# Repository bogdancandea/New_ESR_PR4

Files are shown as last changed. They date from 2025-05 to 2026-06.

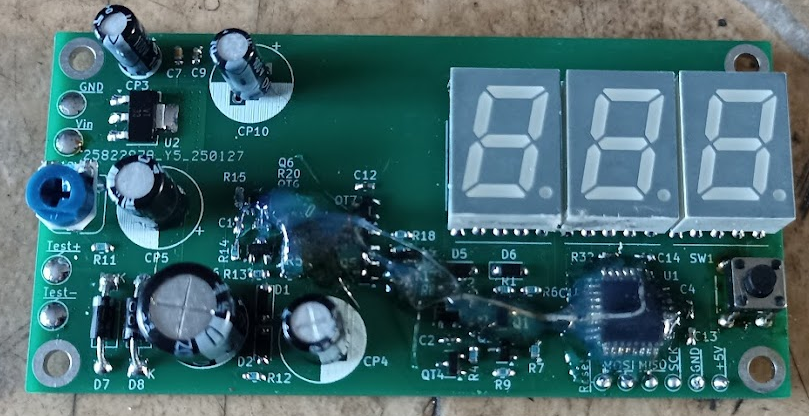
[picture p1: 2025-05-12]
1st build.png

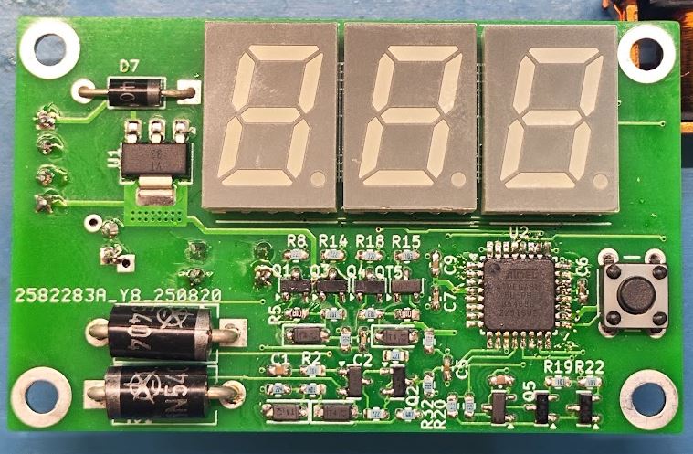
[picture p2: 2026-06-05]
v2 top.jpg

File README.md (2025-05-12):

# New_ESR_PR4
A redesigned PCB for the original ESR-PR4 ESR meter

Back in 2023, my ESR-PR4 broke due to an error (I measured a charged capacitor). My first thought was: oh well, it served me well until now—I'll just get another one. Identical.
However, over the years, the manufacturer had stopped production, and even the website had disappeared.

With some information from specialized forums and with the help of https://web.archive.org, I managed to access an archived version of the website that used to sell the product:

https://web.archive.org/web/20180327142201/http://x-roast.home.ro/

At that time, the author had published both the schematic and the software written for the microcontroller. So I was able to repair my device by replacing and reprogramming the microcontroller.

That’s when I got the idea to republish the information. Since the original information did not include the PCB, I designed a PCB version so that electronics enthusiasts could build the device themselves.

The author of the schematic and the software is unknown to me. I am using and republishing this information because it was publicly available at x-roast.home.ro. I have no commercial interest whatsoever.

There is a mismatch between the original schematic and the HEX file: pins 10 and 11 of the microcontroller are swapped.
The first unit I built had a few errors, including the swapped pins 10 and 11, which were fixed by cutting PCB traces and soldering wires.

The published version has already been corrected.

A new, smaller PCB version is currently in development, which I will publish only after I have had the chance to test it.

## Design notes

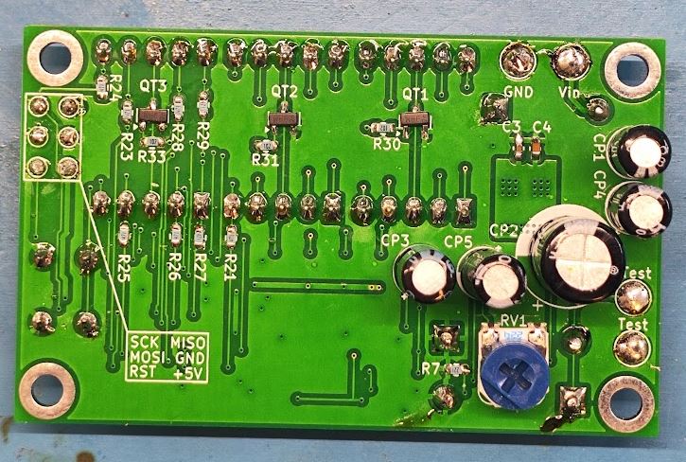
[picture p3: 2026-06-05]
v2 bottom.jpg

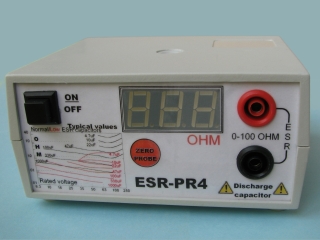
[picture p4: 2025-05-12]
originals/webarchive/ESR metru_ ESR-PR4_files/ESR-METRU ESR-PR4_proto2.JPG

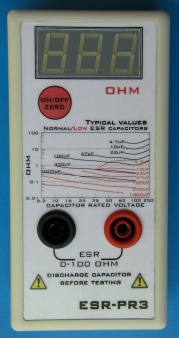
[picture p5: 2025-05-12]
originals/webarchive/ESR metru_ ESR-PR3_files/ESR-METRU ESR-PR3 front view.jpg

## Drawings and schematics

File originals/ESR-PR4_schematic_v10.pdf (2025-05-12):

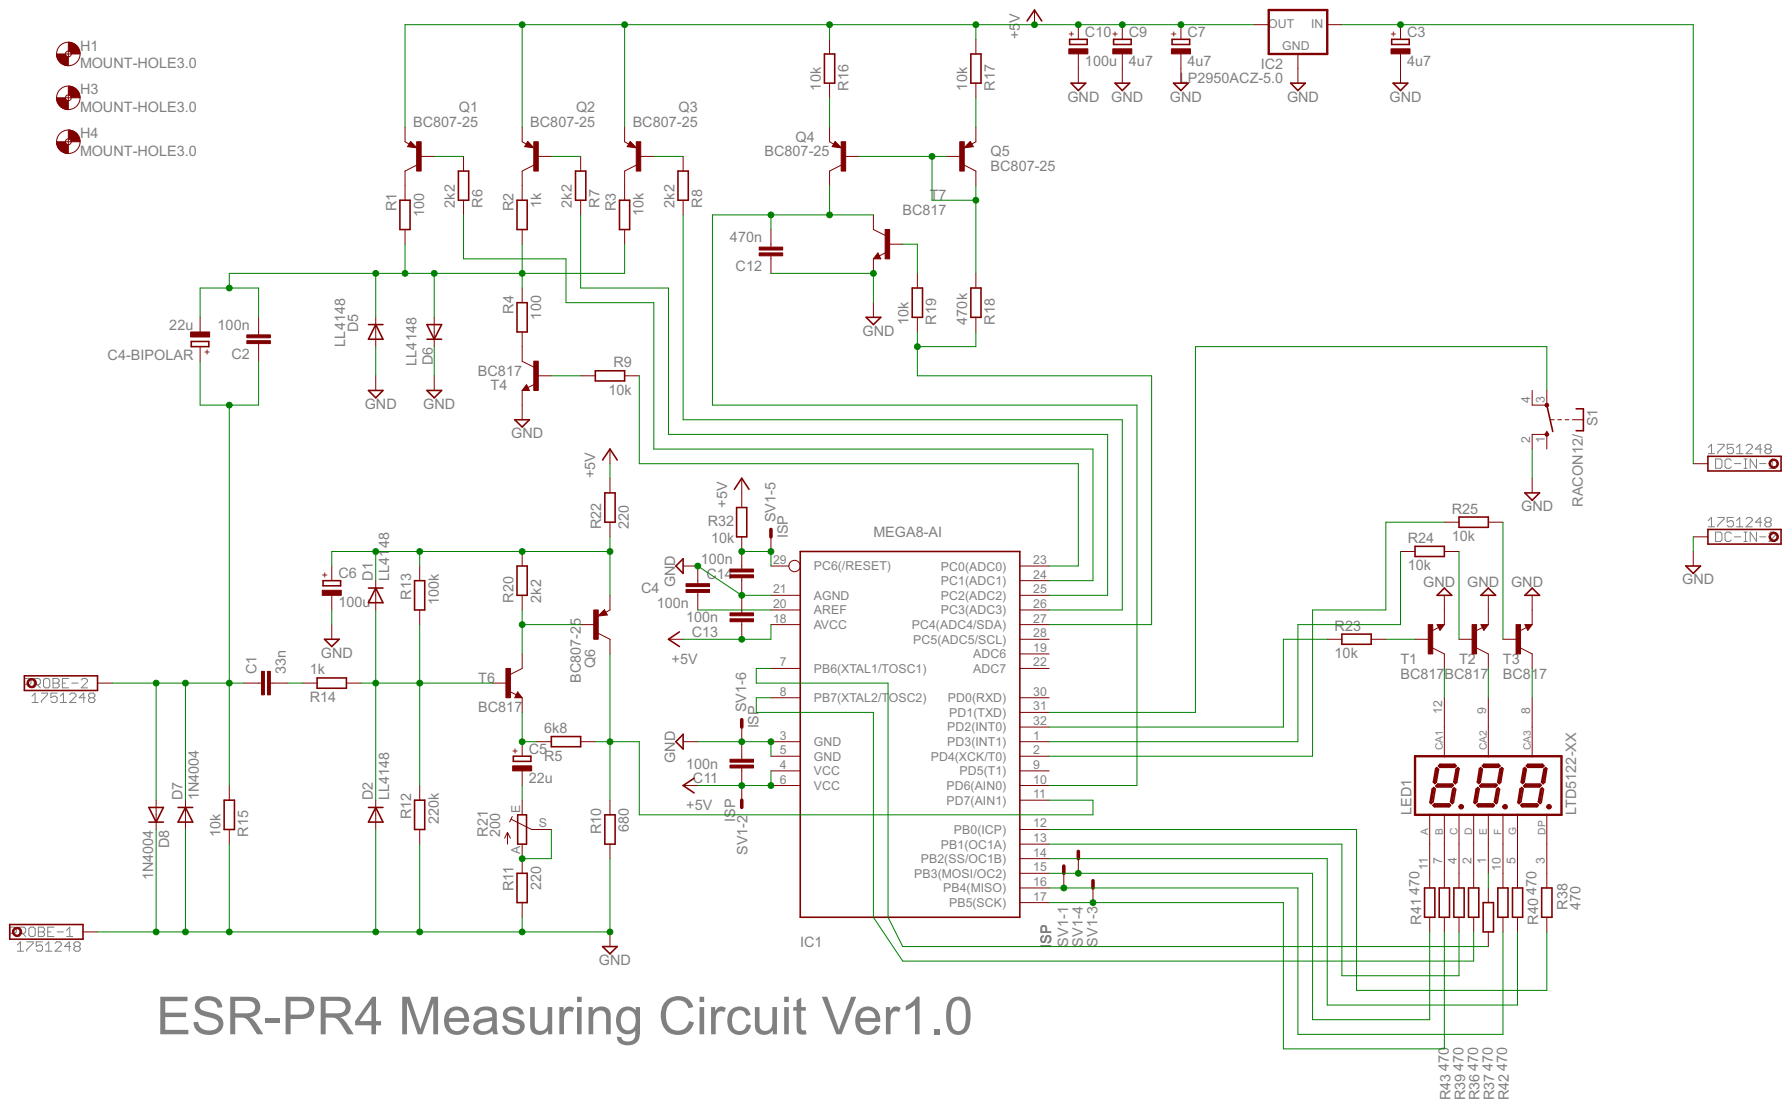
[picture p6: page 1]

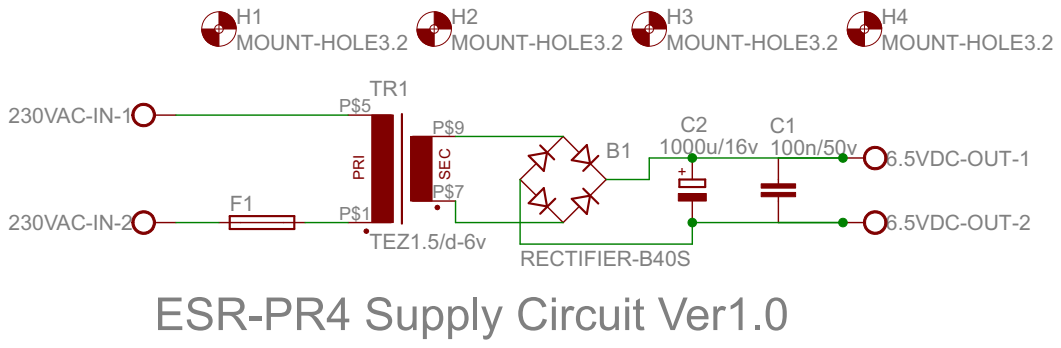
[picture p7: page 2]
TEZ1.5/d-6v; RECTIFIER-B40S; 1000u/16v 100n/50v MOUNT-HOLE3.2; MOUNT-HOLE3.2; MOUNT-HOLE3.2 P$5 P$1; 230VAC-IN-1; 230VAC-IN-2; 6.5VDC-OUT-1; 6.5VDC-OUT-2; PRI SEC

ESR-PR4 Supply Circuit Ver1.0

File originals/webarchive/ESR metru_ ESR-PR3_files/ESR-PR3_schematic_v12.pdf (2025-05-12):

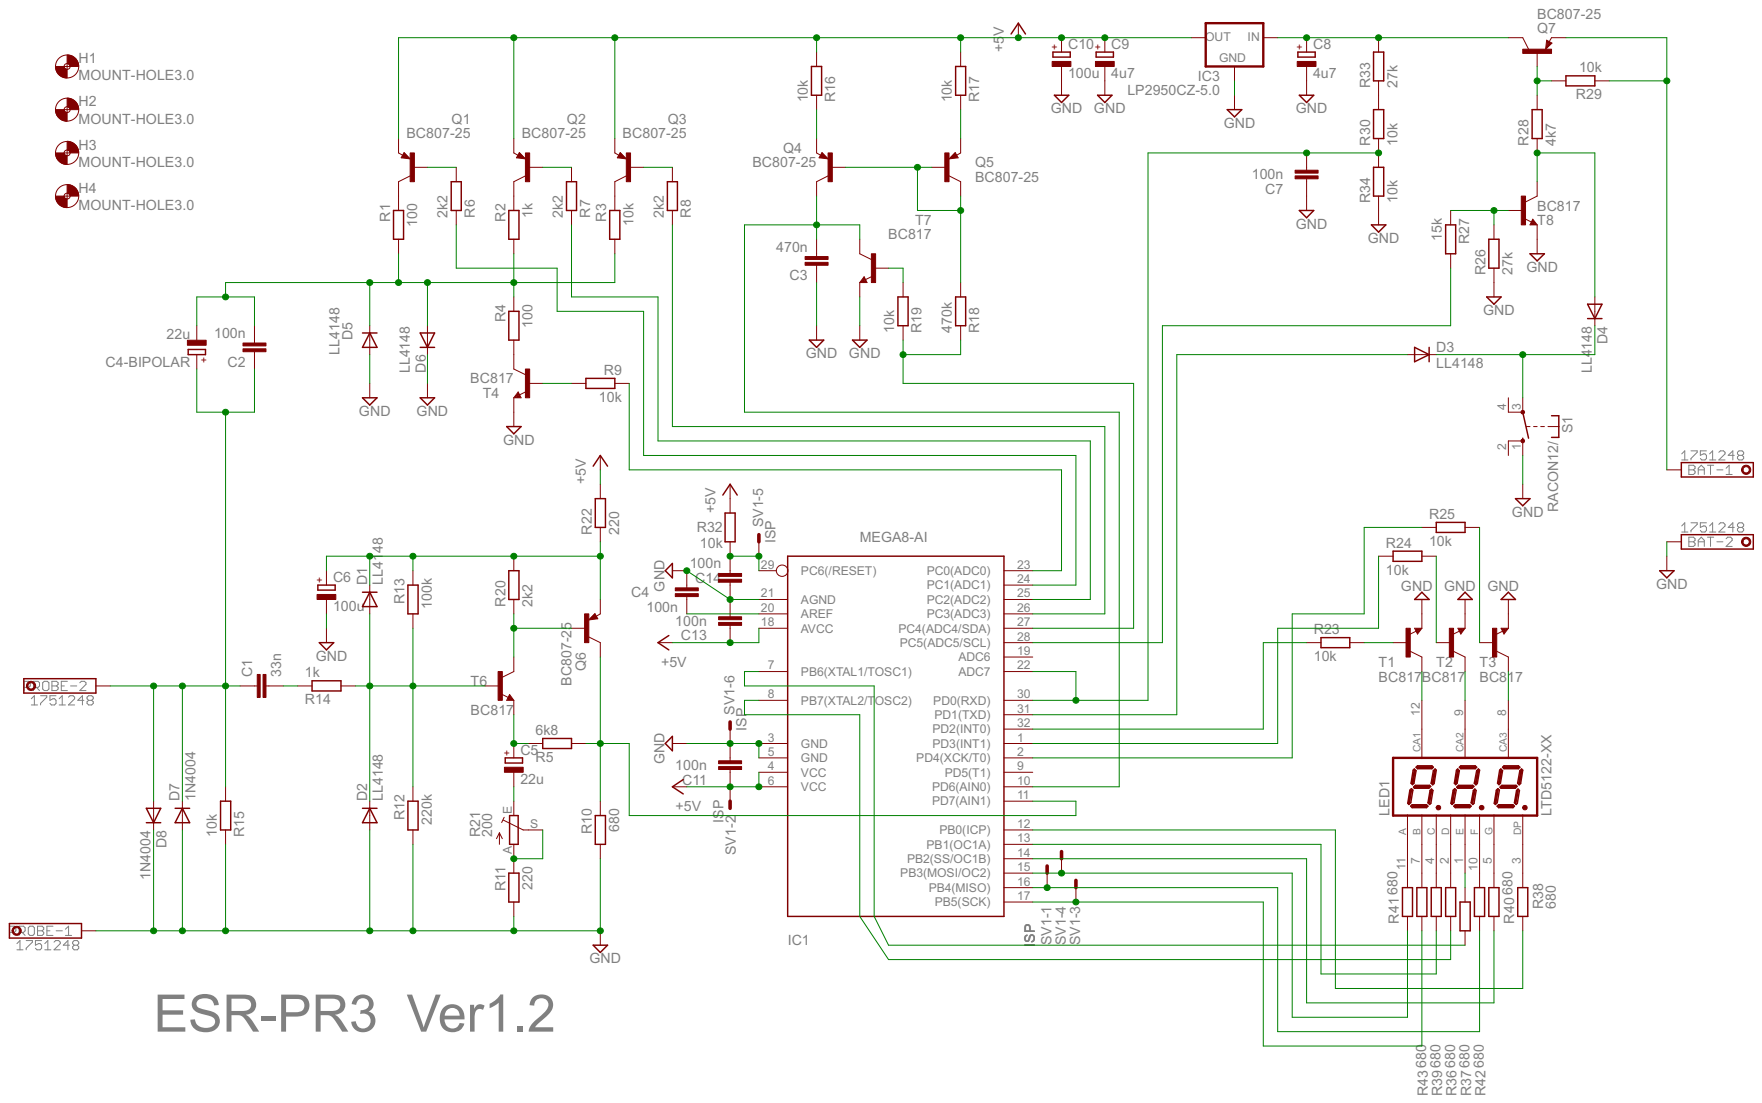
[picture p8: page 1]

MOUNT-HOLE3.0 MOUNT-HOLE3.0

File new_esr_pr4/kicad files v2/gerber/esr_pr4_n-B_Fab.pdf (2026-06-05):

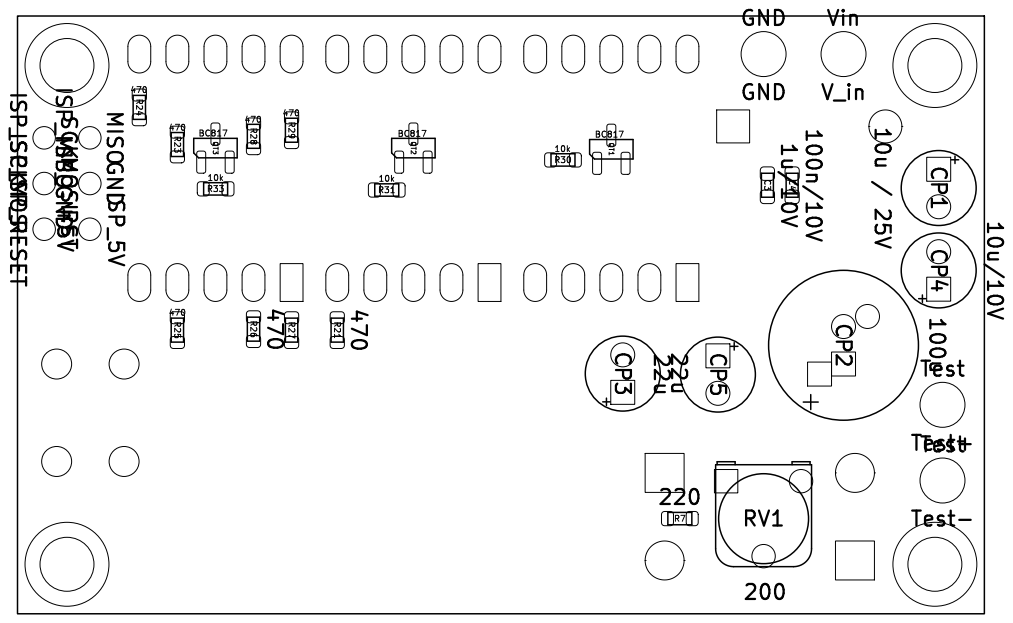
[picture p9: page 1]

Id: 1/1 Title: File: esr_pr4_n.kicad_pcb Sheet: ISP_5V +5V

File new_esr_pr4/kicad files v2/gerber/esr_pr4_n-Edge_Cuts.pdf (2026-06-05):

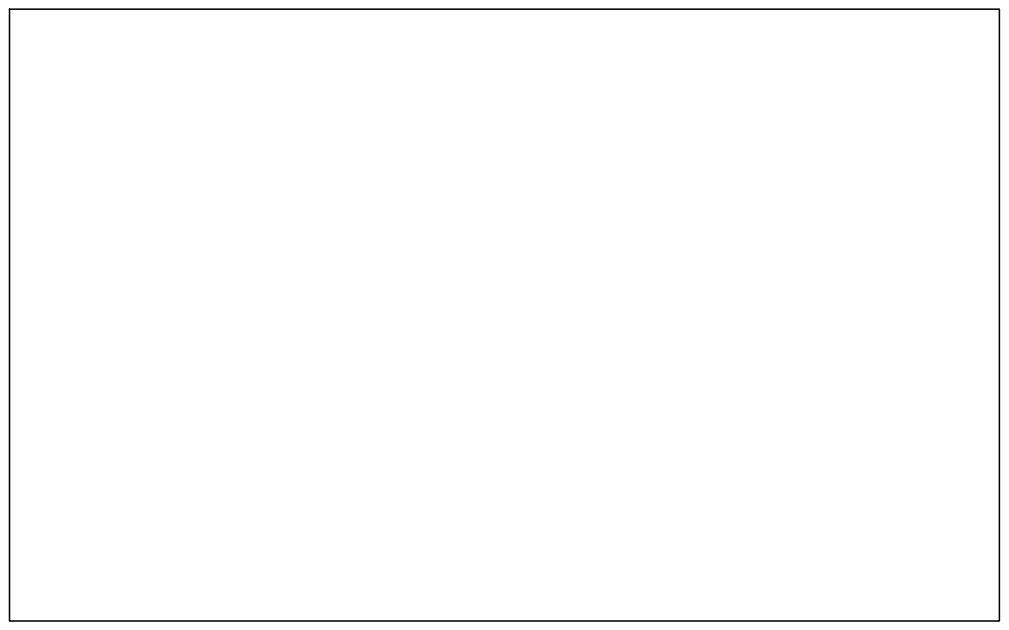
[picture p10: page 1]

Id: 1/1 Title: File: esr_pr4_n.kicad_pcb Sheet:

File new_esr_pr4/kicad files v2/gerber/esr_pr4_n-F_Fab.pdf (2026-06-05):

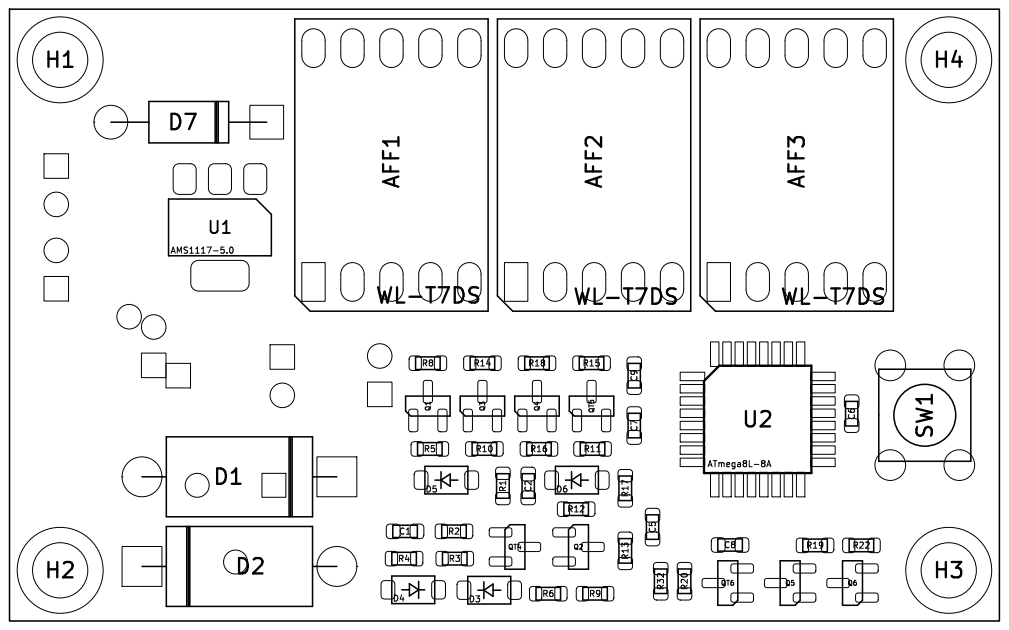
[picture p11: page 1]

Id: 1/1 Title: File: esr_pr4_n.kicad_pcb Sheet:

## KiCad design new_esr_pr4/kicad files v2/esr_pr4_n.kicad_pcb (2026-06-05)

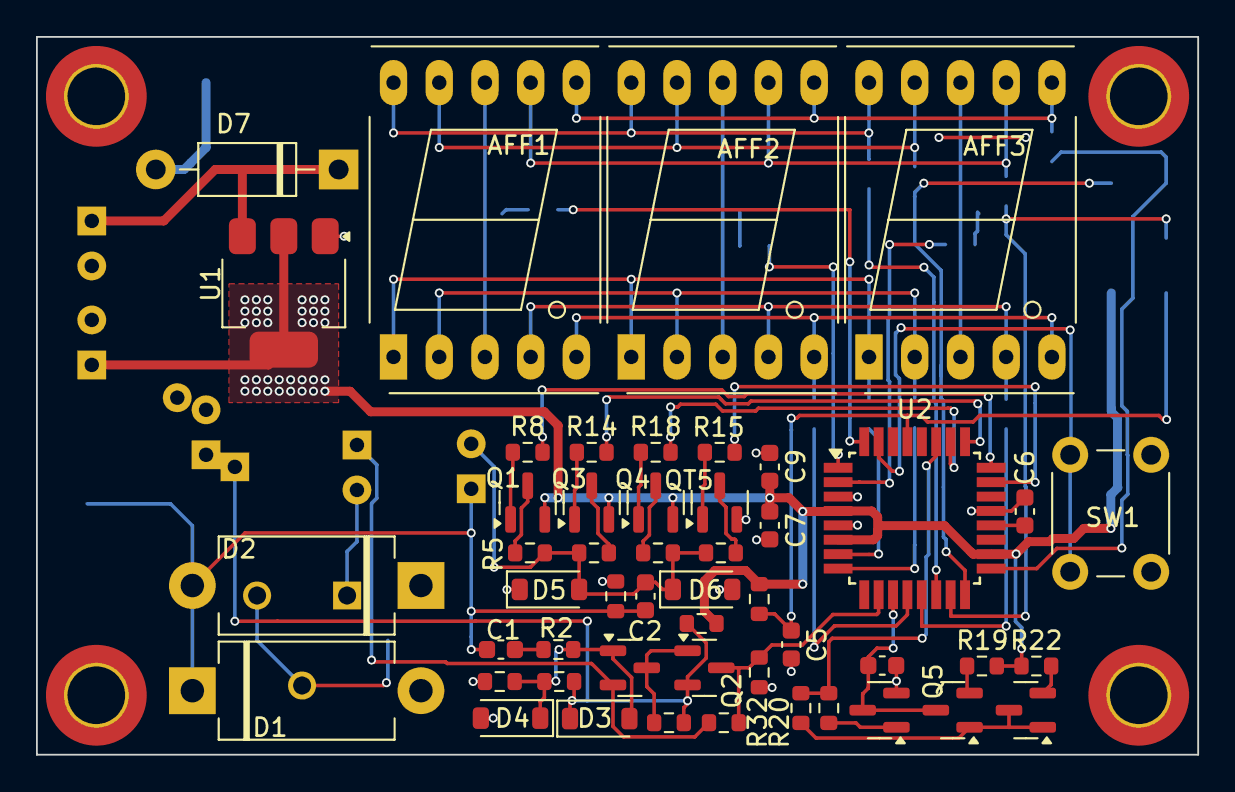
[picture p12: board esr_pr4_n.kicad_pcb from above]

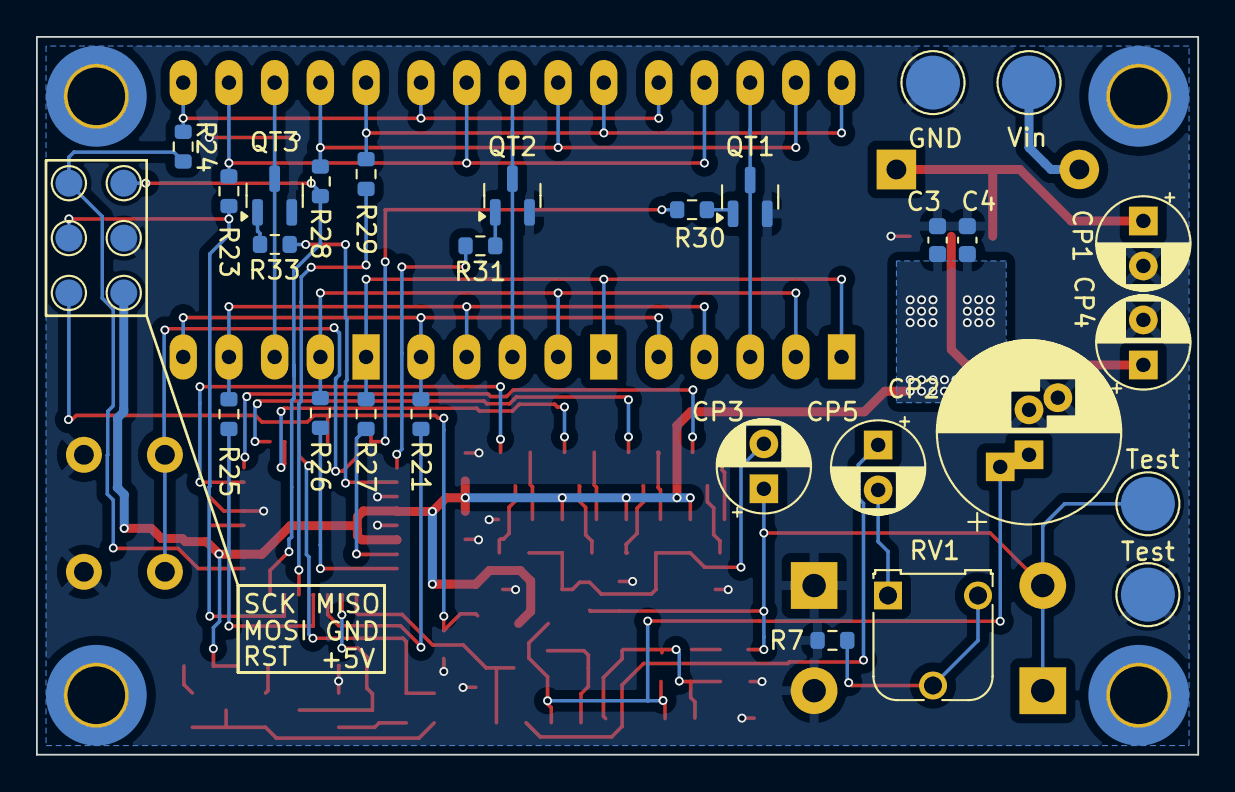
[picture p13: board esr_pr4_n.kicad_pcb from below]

Board: 2 copper layers, 64.5 x 39.9 mm, 87 parts (33 on the bottom side), 60 nets.

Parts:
+5V: ISP_5V; TestPoint_Pad_D1.5mm
AFF1, AFF2, AFF3: WL-T7DS; 7SegmentLED_LTS6760_LTS6780
C1: 33n; C_0603_1608Metric
C2, C5, C6, C7, C9: 100n; C_0603_1608Metric
C3: 1u/10V; C_0603_1608Metric
C4: 100n/10V; C_0603_1608Metric
C8: 470n; C_0603_1608Metric
CP1: 10u / 25V; CP_Radial_D5.0mm_P2.50mm
CP2: 100u; CP_Radial_D10.0mm_P2.50mm_P5.00mm
CP3, CP5: 22u; CP_Radial_D5.0mm_P2.50mm
CP4: 10u/10V; CP_Radial_D5.0mm_P2.50mm
D1, D2: 1N4007; D_DO-201_P12.70mm_Horizontal
D3, D4, D5, D6: 1N4148W; D_SOD-123
D7: 1N4007; D_DO-41_SOD81_P10.16mm_Horizontal
GND: GND; TestPoint_Pad_D3.0mm
GND#2: ISP_GND; TestPoint_Pad_D1.5mm
H1, H2, H3, H4: MountingHole; MountingHole_3.2mm_M3_DIN965_Pad_TopBottom
MISO: ISP_MISO; TestPoint_Pad_D1.5mm
MOSI: ISP_MOSI; TestPoint_Pad_D1.5mm
Q1, Q2, Q3, Q4, Q5, Q6: BC807; SOT-23
QT1, QT2, QT3, QT4, QT5, QT6: BC817; SOT-23
R1, R15, R16, R17, R19, R20, R22, R30, R31, R33: 10k; R_0603_1608Metric
R2, R10: 1k; R_0603_1608Metric
R3: 100k; R_0603_1608Metric
R4: 220k; R_0603_1608Metric
R5, R11: 100; R_0603_1608Metric
R6, R8, R14, R18: 2k2; R_0603_1608Metric
R7, R12: 220; R_0603_1608Metric
R9: 6k8; R_0603_1608Metric
R13: 680; R_0603_1608Metric
R21, R23, R24, R25, R26, R27, R28, R29: 470; R_0603_1608Metric
R32: 470k; R_0603_1608Metric
RST: ISP_RESET; TestPoint_Pad_D1.5mm
RV1: 200; Potentiometer_Runtron_RM-065_Vertical
SCK: ISP_SCK; TestPoint_Pad_D1.5mm
SW1: SW_Push; SW_PUSH_6mm
Test: Test+; TestPoint_Pad_D3.0mm
Test#2: Test-; TestPoint_Pad_D3.0mm
U1: AMS1117-5.0; SOT-223-3_TabPin2
U2: ATmega8L-8A; TQFP-32_7x7mm_P0.8mm
Vin: V_in; TestPoint_Pad_D3.0mm

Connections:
+5V: +5V.1, C3.1, C4.1, C7.2, C9.2, CP4.1, Q1.2 (E), Q3.2 (E), Q4.2 (E), R12.1, R17.1, R19.1, R22.1, U1.2 (VO), U2.4 (VCC), U2.6 (VCC), U2.18 (AVCC)
/constant current/cap_V: C8.1, Q5.3 (C), QT6.3 (C), U2.11 (PD7)
/constant current/discharge: R20.2, R32.2, U2.27 (PC4)
/display/C: R25.1, U2.13 (PB1)
/display/CK1: R30.2, U2.32 (PD2)
/display/CK2: R31.2, U2.1 (PD3)
/display/CK3: R33.2, U2.2 (PD4)
/display/D: R26.1, U2.8 (PB7/XTAL2)
/display/DP: R21.1, U2.12 (PB0)
/display/E: R27.1, U2.7 (PB6/XTAL1)
/display/G: R29.1, U2.14 (PB2)
/main/ADC_ESR: Q2.3 (C), R9.1, R13.1, U2.10 (PD6)
/main/HS1: R8.2, U2.24 (PC1)
/main/HS2: R14.2, U2.25 (PC2)
/main/HS3: R18.2, U2.26 (PC3)
/main/ISP_MISO: MISO.1, R28.1, U2.16 (PB4)
/main/ISP_MOSI: MOSI.1, R23.1, U2.15 (PB3)
/main/ISP_RESET: C5.1, R17.2, RST.1, U2.29 (PC6/~RESET)
/main/ISP_SCK: R24.1, SCK.1, U2.17 (PB5)
/main/LS1: R15.1, U2.23 (PC0)
/measurement circuit/pulse: C1.2, C2.2, CP3.1, D1.2 (A), D2.1 (K), R1.1, Test.1
GND: C3.2, C4.2, C5.2, C6.2, C7.1, C8.2, C9.1, CP1.2, CP2.2, CP4.2, D1.1 (K), D2.2 (A), D4.2 (A), D5.1 (K), D6.2 (A), GND.1, GND#2.1, QT1.2 (E), QT2.2 (E), QT3.2 (E), QT5.2 (E), QT6.2 (E), R1.2, R4.2, R7.2, R13.2, SW1.2, Test#2.1, U1.1 (GND), U2.3 (GND), U2.5 (GND), U2.21 (AGND)
unnamed: AFF1.5 (DP), AFF2.5 (DP), AFF3.5 (DP), R21.2
unnamed: AFF1.7 (a), AFF2.7 (a), AFF3.7 (a), R23.2
unnamed: AFF1.6 (b), AFF2.6 (b), AFF3.6 (b), R24.2
unnamed: AFF1.4 (c), AFF2.4 (c), AFF3.4 (c), R25.2
unnamed: AFF1.2 (d), AFF2.2 (d), AFF3.2 (d), R26.2
unnamed: AFF1.1 (e), AFF2.1 (e), AFF3.1 (e), R27.2
unnamed: AFF1.9 (f), AFF2.9 (f), AFF3.9 (f), R28.2
unnamed: AFF1.10 (g), AFF2.10 (g), AFF3.10 (g), R29.2
unnamed: C1.1, R2.2
unnamed: CP5.2, RV1.1
unnamed: D3.2 (A), D4.1 (K), QT4.1 (B), R2.1, R3.2, R4.1
unnamed: CP2.1, D3.1 (K), Q2.2 (E), R3.1, R6.1, R12.2
unnamed: C2.1, CP3.2, D5.2 (A), D6.1 (K), R5.2, R10.2, R11.1, R16.2
unnamed: D7.2 (A), Vin.1
unnamed: CP1.1, D7.1 (K), U1.3 (VI)
unnamed: Q1.1 (B), R8.1
unnamed: Q1.3 (C), R5.1
unnamed: Q2.1 (B), QT4.3 (C), R6.2
unnamed: Q3.1 (B), R14.1
unnamed: Q3.3 (C), R10.1
unnamed: Q4.1 (B), R18.1
unnamed: Q4.3 (C), R16.1
unnamed: Q5.1 (B), Q6.1 (B), Q6.3 (C), R32.1
unnamed: Q5.2 (E), R19.2
unnamed: Q6.2 (E), R22.2
unnamed: QT1.1 (B), R30.1
unnamed: AFF1.3 (C.A.), AFF1.8 (C.A.), QT1.3 (C)
unnamed: QT2.1 (B), R31.1
unnamed: AFF2.3 (C.A.), AFF2.8 (C.A.), QT2.3 (C)
unnamed: QT3.1 (B), R33.1
unnamed: AFF3.3 (C.A.), AFF3.8 (C.A.), QT3.3 (C)
unnamed: CP5.1, QT4.2 (E), R9.2
unnamed: QT5.1 (B), R15.2
unnamed: QT5.3 (C), R11.2
unnamed: QT6.1 (B), R20.1
unnamed: R7.1, RV1.2, RV1.3
unnamed: C6.1, U2.20 (AREF)
unnamed: SW1.1, U2.31 (PD1)
